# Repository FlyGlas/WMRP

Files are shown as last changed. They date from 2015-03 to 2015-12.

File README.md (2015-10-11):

# Hardware and Arduino Code for DIY WMRP-Solder Station

Video: https://www.youtube.com/watch?v=le2HaKJ6B1A

If you have any questions, please feel free to contact me: flyglas (at) gmail (dot) com

__Features:__
* low offset op amp for soldering tip temperature measurement with type D thermocouple
* cold junction compensation using the PTC (KTY82-110) included in the WMRP soldering pencil
* input voltage measurement (for use with 3 cell lipo battery)
* soldering pencil current measurement 
* recognizing if the soldering pencil rests in the stand (--> standby)
* 3 buttons for save and recall temperature values
* rotary encoder to set soldering temperature
* illuminated 16x2 character LCD module
* USB for debugging and firmware update
* clean and small enclosure
* 4mm safety socket for +12V power input and a protective earth socket for connection to ESD protection

The BOM in the layout folder includes only the parts on the PCB(s).

__Parts (not on PCB):__
* lcd display from ebay "Blue I2C 1602"
* modified connector "Amphenol T 3437 000" (--> http://www.mikrocontroller.net/topic/143288#1500819)
* 4mm safety sockets (red, black, green/yellow) or any other suitable connector
* rotary encoder knob
* display frame "EA027-2UKE"
* aluminium enclosure "Proma 131020"

__Info:__
* close jumper JP1 (activates pullup resistors for I2C wires)
* close jumper JP3 (connection between power ground and analog ground)
* leave jumper JP2 open (alternative for JP3)

__Photos:__
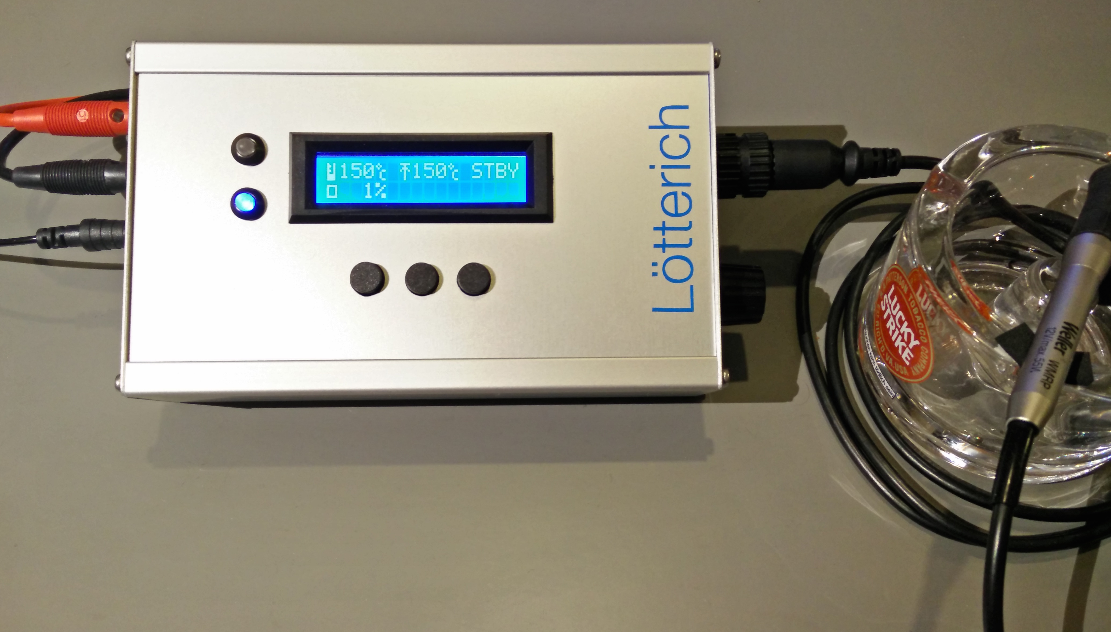
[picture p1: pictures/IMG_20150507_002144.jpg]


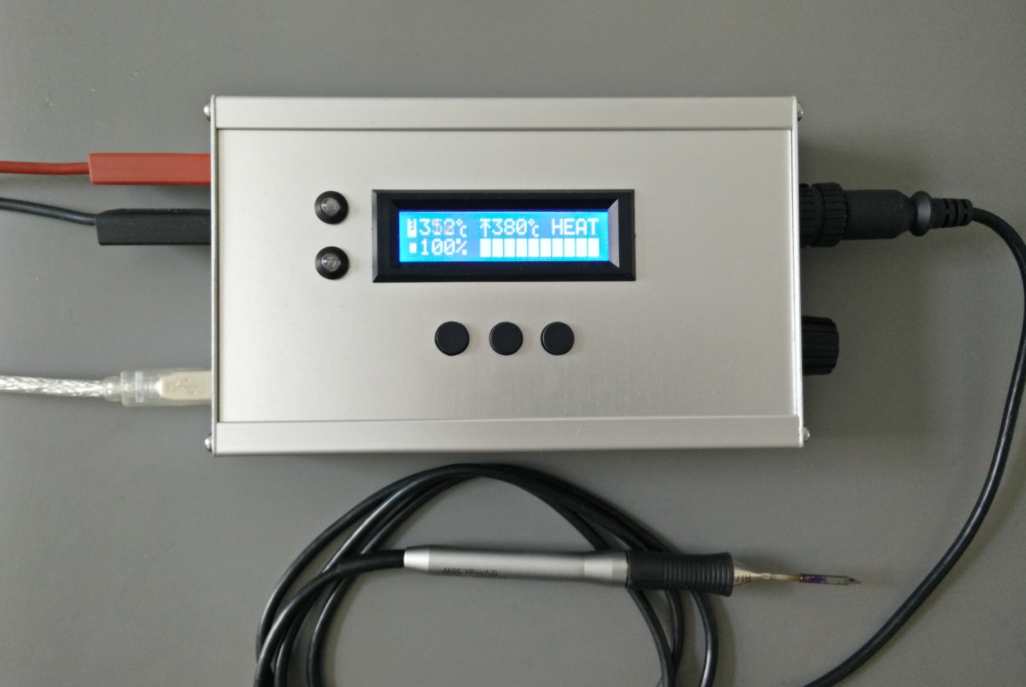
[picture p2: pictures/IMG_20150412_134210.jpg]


The PCB is a little bit dirty. The Isopropanol was empty and now everything is in the enclosure.
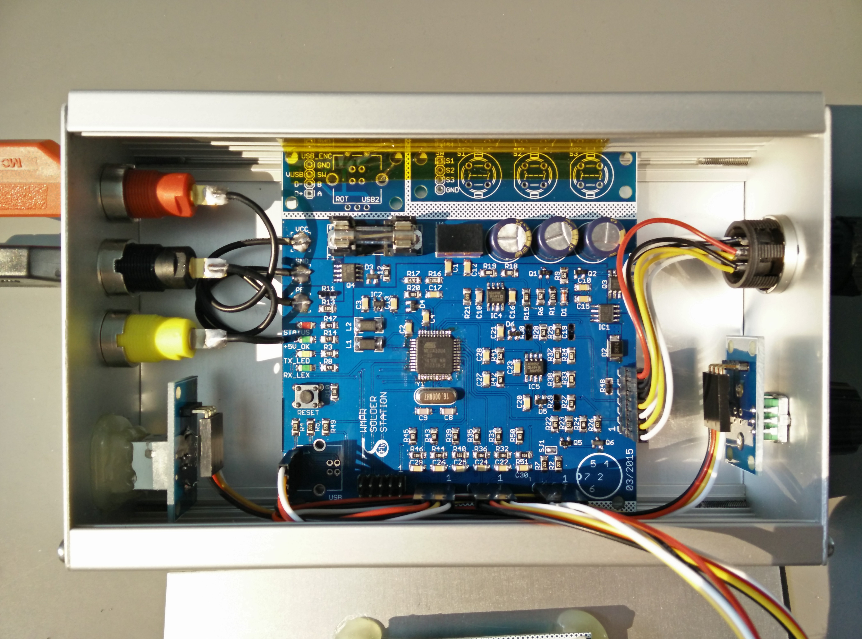
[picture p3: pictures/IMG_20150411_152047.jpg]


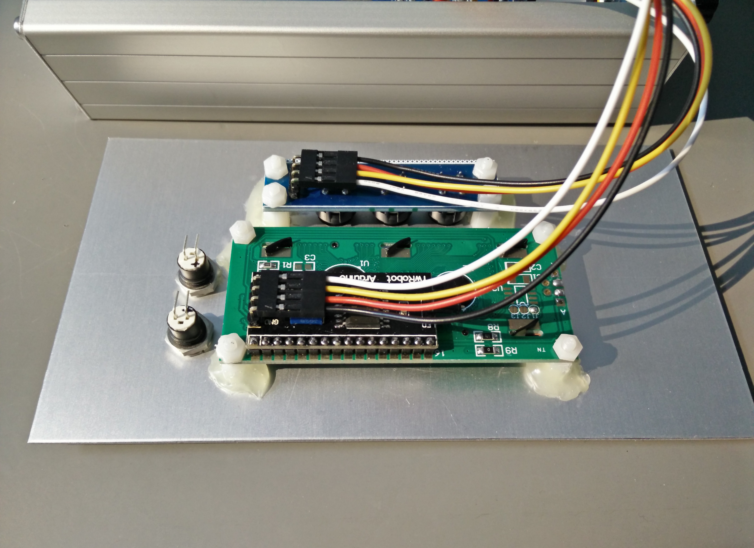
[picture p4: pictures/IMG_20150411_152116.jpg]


Stand for enclosure Proma 131020:
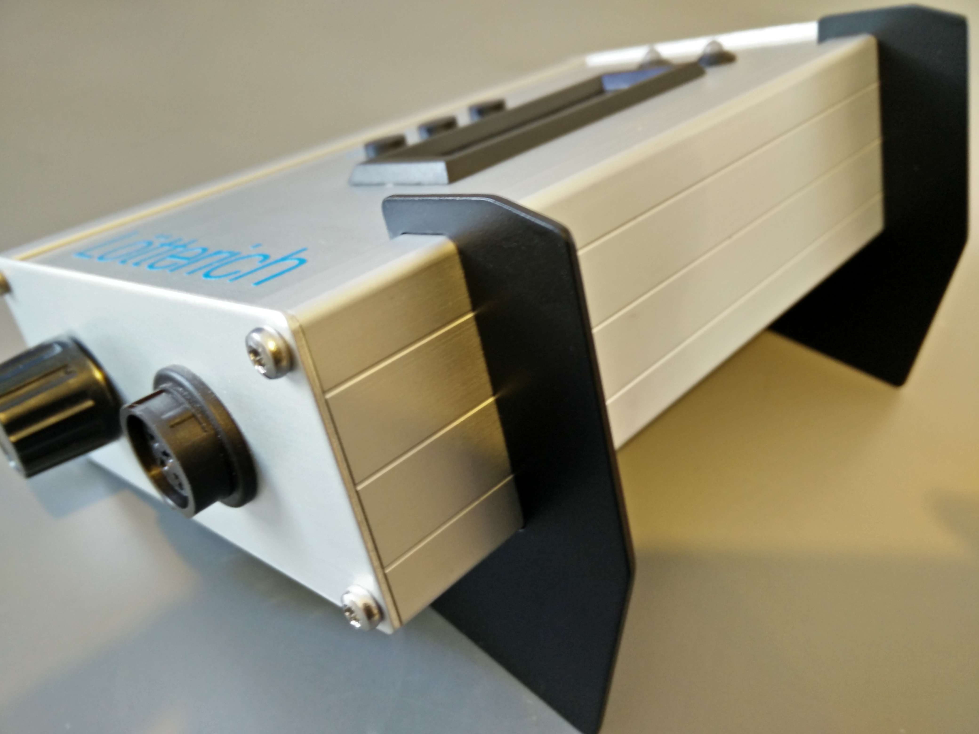
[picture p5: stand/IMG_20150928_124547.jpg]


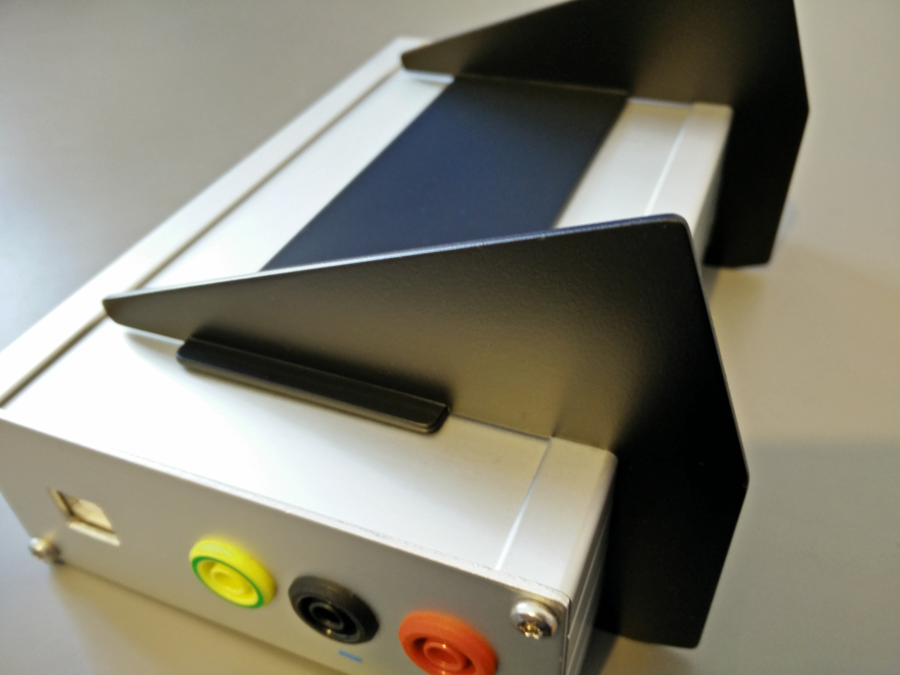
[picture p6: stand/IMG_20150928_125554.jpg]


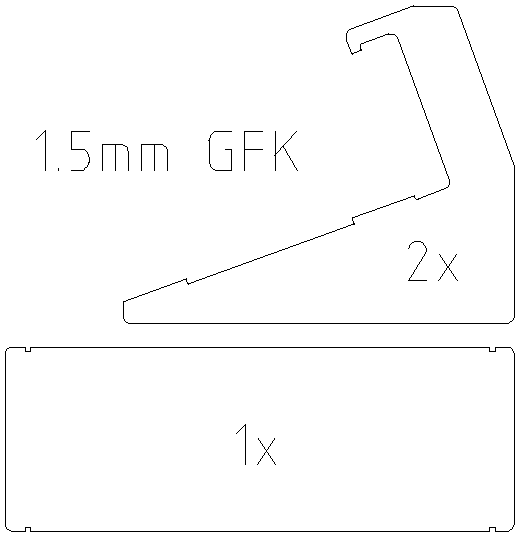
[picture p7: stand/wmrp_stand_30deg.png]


__First picture of a replica:__

Thank you Dennis for the nice conversation and the picture.
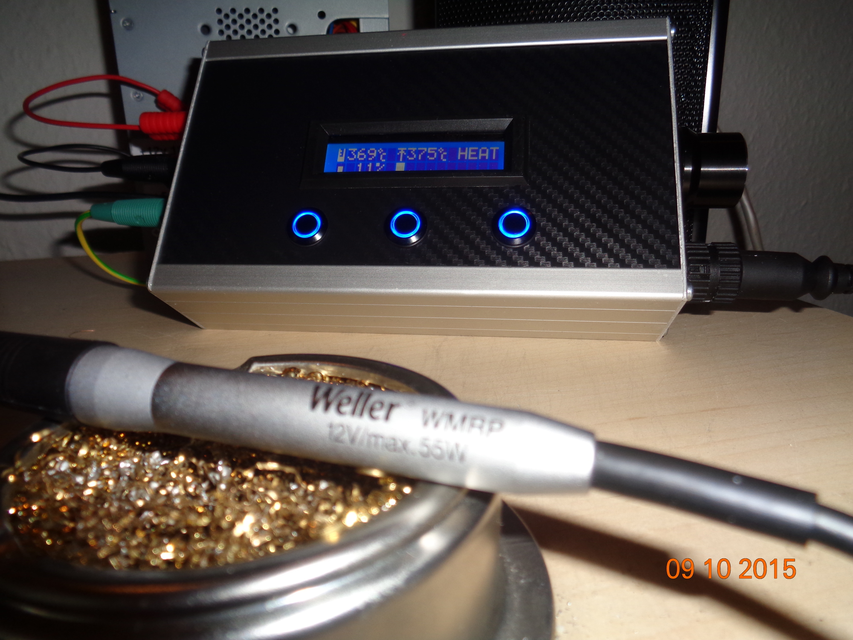
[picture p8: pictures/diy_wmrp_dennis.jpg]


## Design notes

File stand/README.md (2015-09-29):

This folder contains pictures of the stand and the dxf-file for production.

The three parts of the stand were milled from a 1.5mm GFRP-plate, glued together with cyanoacrylate adhesive and painted with matt black spray paint.

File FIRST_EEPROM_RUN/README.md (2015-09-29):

This arduino sketch writes the default temperature value of 375 deg C to the whole EEPROM of the microcontroller.
First-time operation is also possible without loading this sketch.

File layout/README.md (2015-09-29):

This folder contains the original eagle board data and schematic diagram, gerbers, bill of materials, schematic diagram as pdf and component mounting diagram.

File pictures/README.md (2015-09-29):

This folder contains pictures of the diy wmrp soldering station and the pin assignment/internal circuit of the wmrp handle.

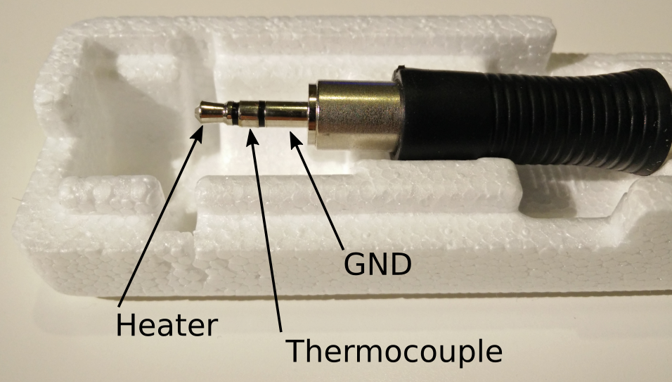
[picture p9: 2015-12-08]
pictures/tip_connector.png

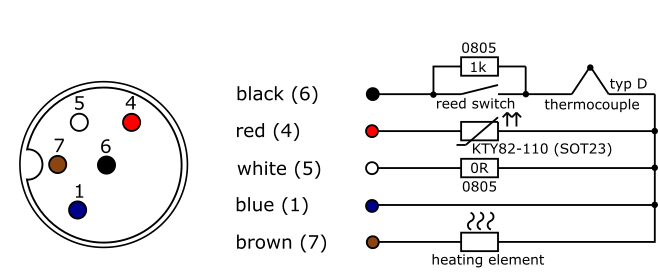
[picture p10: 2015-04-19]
pictures/pin_assignment_wmrp_en.png

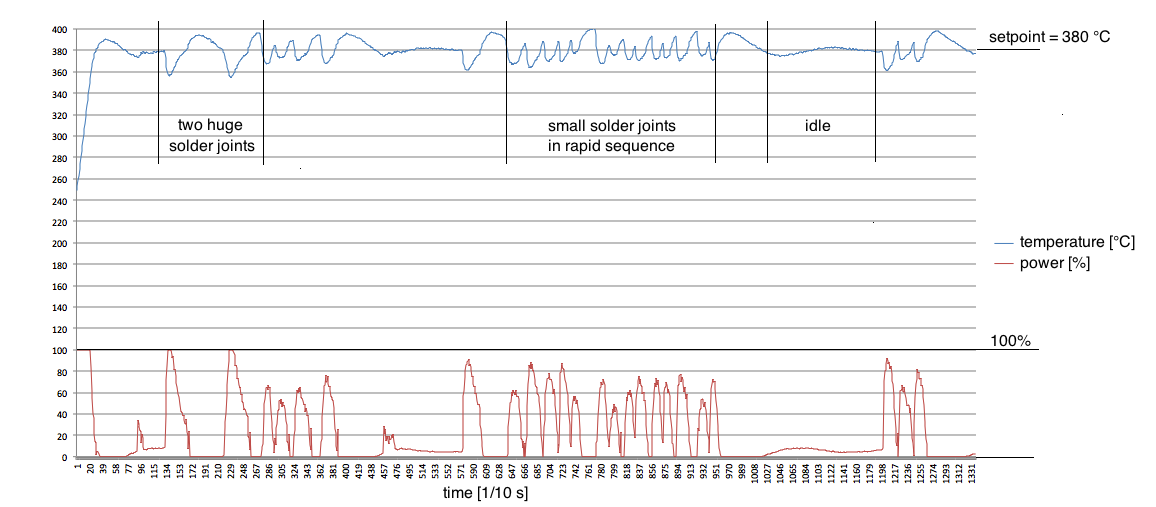
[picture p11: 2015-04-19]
pictures/temp_power_diagram.png

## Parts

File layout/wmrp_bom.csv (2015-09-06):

Qty | Value | Device | Package | Parts | Description | CONRAD | REICHELT | VOELKNER | FARNELL
1 | 100R 0.1% | R-EU_M1206 | M1206 | R33 | RESISTOR; European symbol |  | SPR-1206 100
2 | 100k | R-EU_R1206 | R1206 | R1; R22 | RESISTOR; European symbol |  | SMD 1/4W 100K
2 | 100k 0.1% | R-EU_M1206 | M1206 | R18; R19 | RESISTOR; European symbol |  | SPR-1206 100K
13 | 100n | C-EUC1206 | C1206 | C1; C2; C3; C4; C6; C10; C12; C13; C15; C16; C17; C23; C32 | CAPACITOR; European symbol |  | X7R-G1206 100N
16 | 10k | R-EU_R1206 | R1206 | R10; R12; R20; R24; R31; R32; R35; R36; R39; R40; R43; R44; R45; R46; R50; R51 | RESISTOR; European symbol |  | SMD 1/4W 10K
2 | 10k 0.1% | R-EU_M1206 | M1206 | R34; R37 | RESISTOR; European symbol |  | SPR-1206 10;0K
10 | 10n | C-EUC1206 | C1206 | C20; C21; C22; C24; C25; C26; C27; C28; C29; C30 | CAPACITOR; European symbol |  | X7R-G1206 10N
2 | 10u | INDUCTOR1206H* | INDUCTOR-1206 | L1; L2 | Inductors |  | L-1812AF 10åµ
1 | 12V | ZENER-DIODESOT23 | SOT23 | D3 | Z-Diode |  | SMD ZD 12
1 | 12k 0.1% | R-EU_R1206 | R1206 | R16 | RESISTOR; European symbol |  | SPR-1206 12;0K
1 | 16Mhz | CRYSTALHC49US | HC49US | Y1 | Various standard crystals. Proven footprints. |  | 16;0000-HC49U-S
1 | 1M | R-EU_R1206 | R1206 | R13 | RESISTOR; European symbol |  | SMD 1/4W 1;0M
1 | 1N4148 | DIODE-MINIMELF | MINIMELF | D1 | DIODE |  | 1N 4148 SMD
1 | 1k 0.1% | R-EU_M1206 | M1206 | R15 | RESISTOR; European symbol |  | SPR-1206 1;00K
1 | 1n | C-EUC1206 | C1206 | C18 | CAPACITOR; European symbol |  | NPO-G1206 1;0N
1 | 1u | C-EUC1206 | C1206 | C5 | CAPACITOR; European symbol |  | X7R-G1206 1;0/50
3 | 22R | R-EU_R1206 | R1206 | R4; R5; R49 | RESISTOR; European symbol |  | SMD 1/4W 22
2 | 22p | C-EUC1206 | C1206 | C8; C9 | CAPACITOR; European symbol |  | NPO-G1206 22P
3 | 2k2 | R-EU_R1206 | R1206 | R2; R7; R26 | RESISTOR; European symbol |  | SMD 1/4W 2;2K
2 | 2k2 0.1% | R-EU_M1206 | M1206 | R21; R25 | RESISTOR; European symbol |  | SPR-1206 2;20K
3 | 330u | CAP_POLPTH4 | CPOL-RADIAL-1000UF-25V | C7; C11; C14 | Capacitor Polarized |  | RAD FC 330/25
1 | 3R6 | R-EU_M1206 | M1206 | R52 | RESISTOR; European symbol |  | SMD 1/4W 3;6
1 | 3n3 | C-EUC1206 | C1206 | C31 | CAPACITOR; European symbol |  | X7R-G1206 3;3N
1 | 43k 0.1% | R-EU_M1206 | M1206 | R38 | RESISTOR; European symbol |  | SPR-1206 43;0K
4 | 470R | R-EU_R1206 | R1206 | R3; R8; R14; R47 | RESISTOR; European symbol |  | SMD 1/4W 470
1 | 4k7 0.1% | R-EU_R1206 | R1206 | R17 | RESISTOR; European symbol |  | SPR-1206 4;70K
7 | 5k6 | R-EU_M1206 | M1206 | R6; R9; R23; R27; R28; R41; R42 | RESISTOR; European symbol |  | SMD 1/4W 5;6K
1 | 6A | SH22;5 | SH22;5 | F1 | FUSE HOLDER grid 22;5 mm; OGN0031 8201; Schurter (Buerklin) |  | PL OGN-22;5
1 | ACS712ELCTR-20A-T | ACS712 | SO08 | IC1 | Hall-effect-based isolated linear current sensor |  |  |  | ACS712ELCTR-20A-T
2 | AD8552 | OPAMP-DUALU | SO08 | IC4; IC5 | Generic op-amp footprint |  | AD 8552 AR
1 | ADR392 | ADR392 | SOT23-5 | IC2 | 4.096 V Micropower; Low Noise Precision Voltage Reference with Shutdown | 1250814 - 62 |  | A376911
1 | ATMEGA32U4TQFP-44 | ATMEGA32U4TQFP-44 | TQFP44 | IC3 | Atmel 44-pin 8-bit Microcontroller with 32KBytes of ISP Flash and USB Controller |  |  | A886841
1 | AVR_SPI_PROG | AVR_SPI_PROG | AVR_ICSP | ISP | AVR 10-pin ICSP Header |  | MPE 087-2-010
1 | B240F | MBRS130LT3 | SMB | D2 | Schottky Power Rectifier |  | B 240 F
3 | BAV99 | BAV99 | SOT23 | D4; D5; D6 | Small Signal Diode |  | BAV 99 SMD
3 | BC817-40 | TRANSISTOR_NPNSOT23-3 | SOT23-3 | Q1; Q2; Q5 | Generic NPN BJT |  | BC 817-40 SMD
3 | DT6 | DT6 | DT6 | S1; S2; S3 | ITT SWITCH |  |  | D76189
1 | IRF7413 | IRF7413 | SO-08 | Q4 | N-Channel HEXFETå¨ Power MOSFET |  | IRF 7413
1 | IRF7416 | IRF7416 | SO-08 | Q3 | P-Channel HEXFETå¨ Power MOSFET |  | IRF 7416
1 | IRLML6402 | MOSFET-PCHANNELSMD | SOT23-3 | Q6 | Generic PMOSFET |  | IRLML 6402
1 | ROTARTY_ENCODER | ROTARTY_ENCODER | ROTARY_ENC_PLAIN | ROT | Simple no LED rotary encoder |  |  | W32173
1 | SW | SWITCH-MOMENTARY-2PTH | TACTILE-PTH | RESET | Various NO switches- pushbuttons; reed; etc |  | TASTER 9302
1 | TSR_1-2450 | TSR_1-2450 | TSR-1 | U1 | TRACO TSR-1 Series |  | TSR 1-2450
1 | USB-B | USBPTH | USB-B-PTH | USB | USB Connectors |  | USB BW
1 | USBPTH-VERTICAL | USBPTH-VERTICAL | USB-B-PTH-VERTICAL | USB2 | USB Connectors |  | USB BG
2 | green | LEDCHIPLED_1206 | CHIPLED_1206 | +5V_OK; RX_LEX | LED |  | SMD-LED 1206 GN
1 | red | LEDCHIPLED_1206 | CHIPLED_1206 | STATUS | LED |  | SMD-LED 1206 RT
1 | yellow | LEDCHIPLED_1206 | CHIPLED_1206 | TX_LED | LED |  | SMD-LED 1206 GE
1 | DO NOT INSTALL | C-EUC1206 | C1206 | C19 | CAPACITOR; European symbol
2 | DO NOT INSTALL | R-EU_M1206 | M1206 | R29; R30 | RESISTOR; European symbol
2 | DO NOT INSTALL | R-EU_R1206 | R1206 | R11; R48 | RESISTOR; European symbol

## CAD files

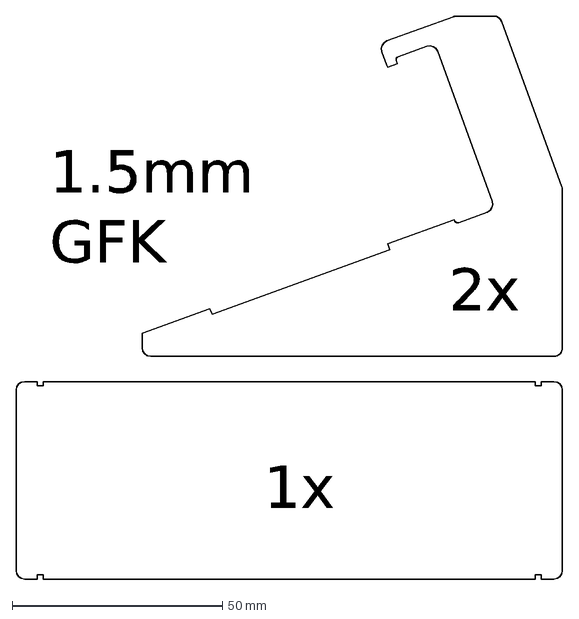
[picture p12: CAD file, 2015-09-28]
stand/wmrp_stand_30deg.dxf
2x
1.5mm GFK
1x

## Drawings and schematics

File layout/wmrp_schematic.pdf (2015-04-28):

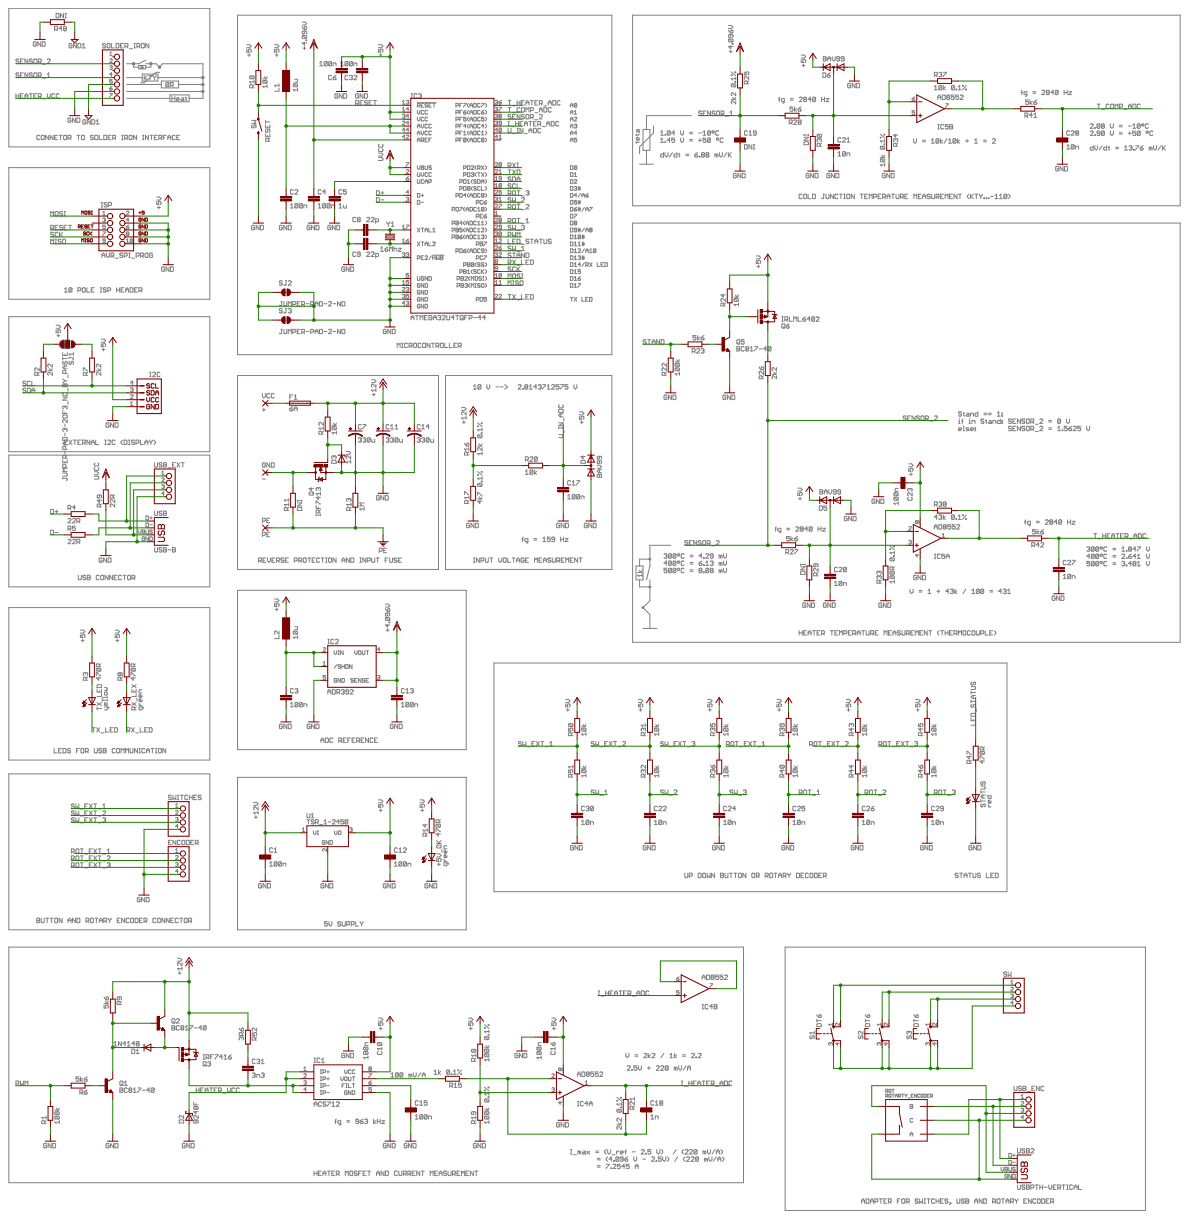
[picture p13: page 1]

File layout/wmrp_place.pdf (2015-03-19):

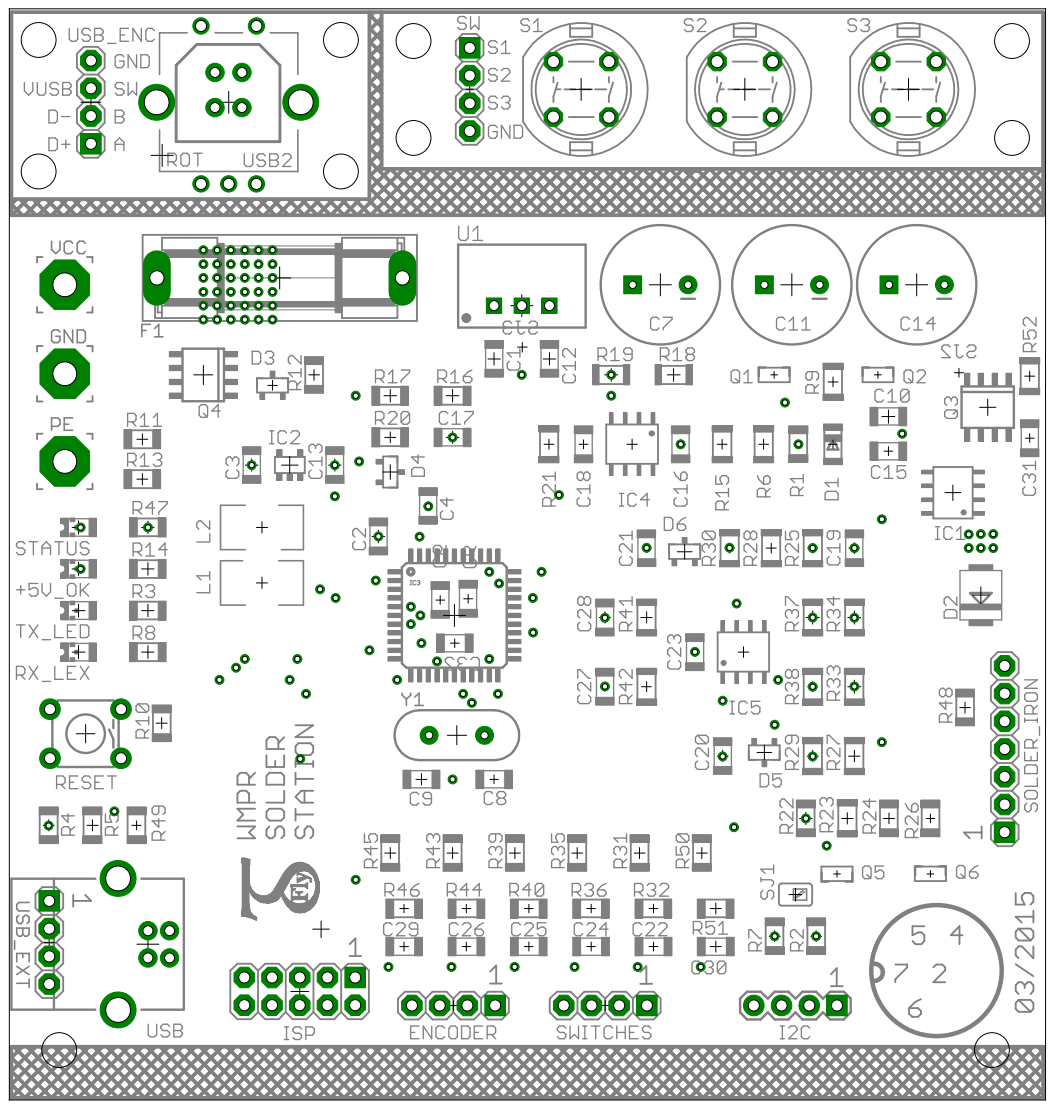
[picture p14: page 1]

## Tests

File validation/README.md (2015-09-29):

This folder contains the measurements of the turn-on und off behavior of the highside switch with and without a RC-snubber circuit.

Settling time of the thermocouple amplifier output in the heating pause is about 1.8 ms (without picture). The settling time is taken into account in the source code with a heating pause before the measurement.

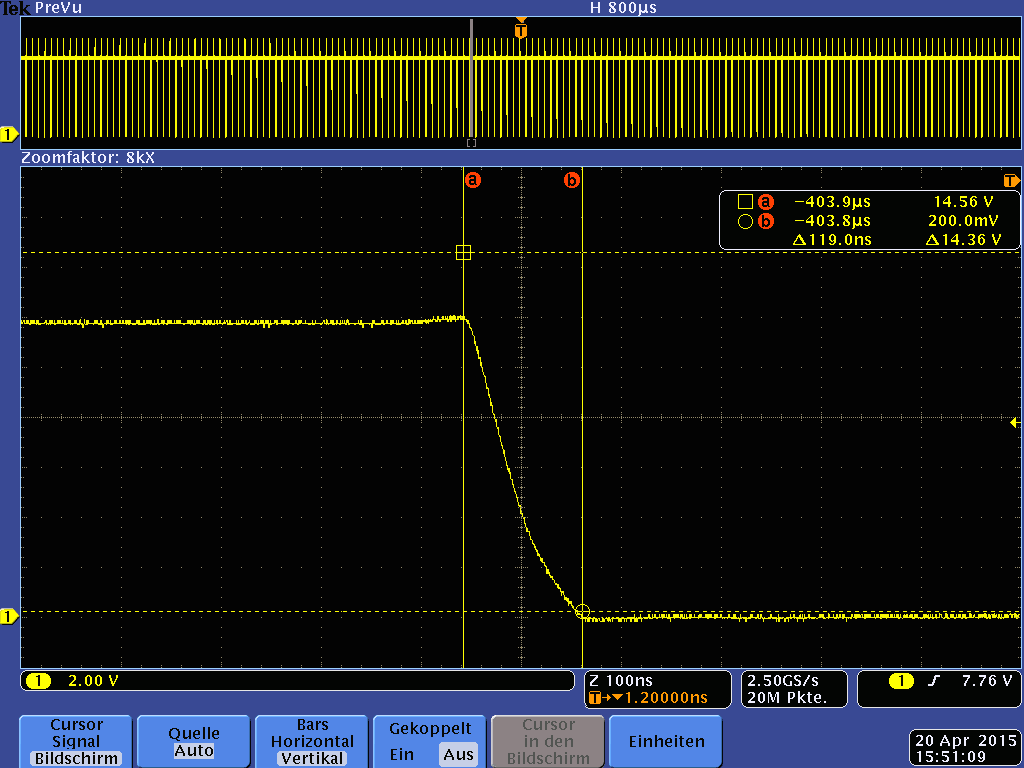
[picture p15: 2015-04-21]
validation/RC_Snubber_3n3_3R6/turn_on.png

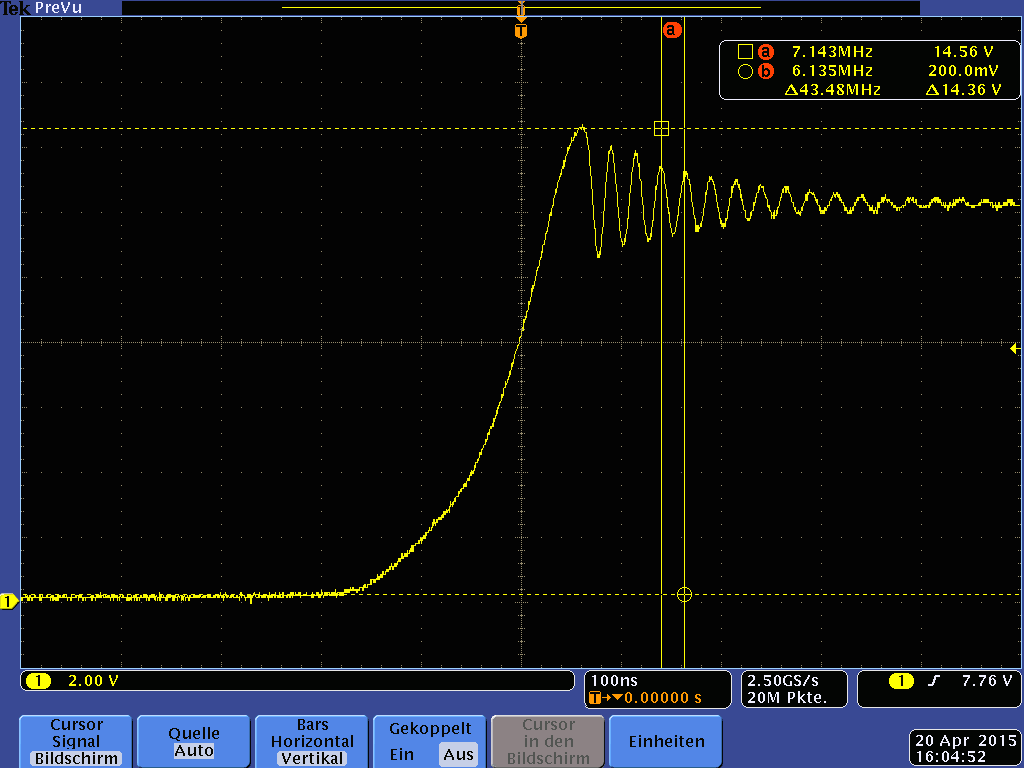
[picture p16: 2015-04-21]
validation/RC_Snubber_3n3_3R6/turn_off_without_snubber.png

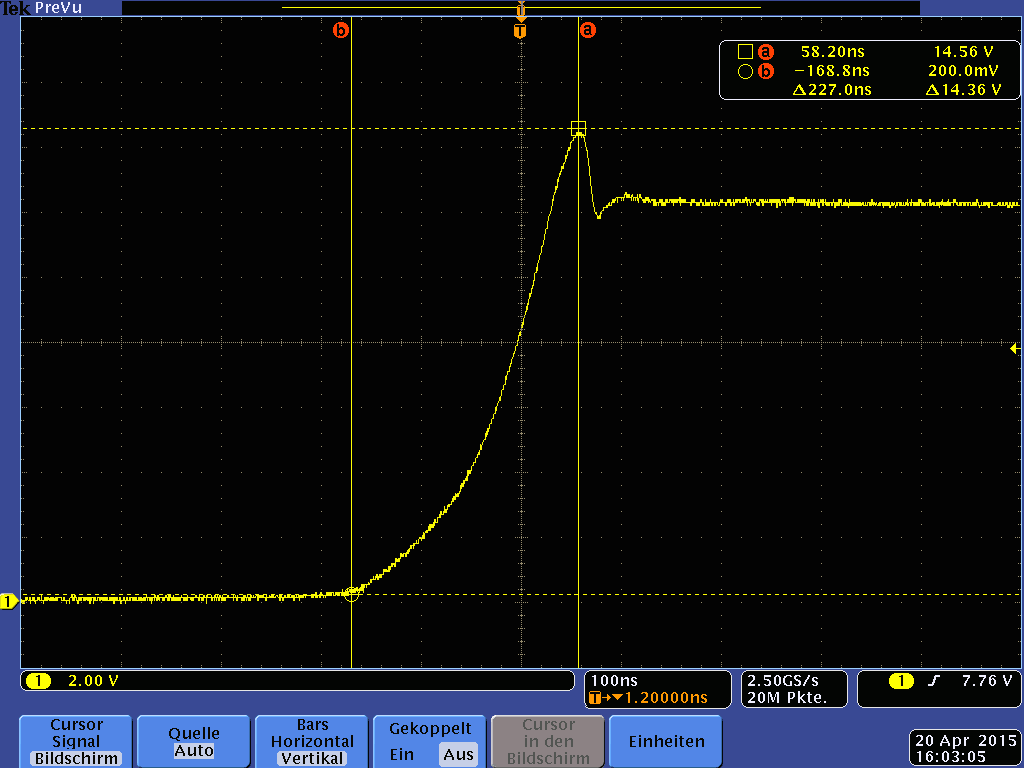
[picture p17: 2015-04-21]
validation/RC_Snubber_3n3_3R6/turn_off_with_snubber.png

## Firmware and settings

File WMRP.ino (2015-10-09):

// some preprocessor defines
#define SW_VERSION      "Version 1.3c"
#define DEBUG           true
//DIGITAL INPUT PINS
// Values after the // are the one for my pcb. Other for debugging on Arduino Uno!
#define PIN_SW_1         12
#define PIN_SW_2         5
#define PIN_SW_3         9
#define PIN_ROT_A        8
#define PIN_ROT_B        6
#define PIN_ROT_SW       4

#define DEBUG_LED        11 // STATUS_LED

//ADC INPUT PINS
#define PIN_ADC_T_GRIP   A1
#define PIN_ADC_T_TIP    A0
#define PIN_ADC_U_IN     A4
#define PIN_ADC_I_HEATER A3
#define PIN_ADC_STAND    A2

//OUTPUT PINS
#define PIN_HEATER       10
#define PIN_STAND        13
//#define PIN_I2C_SDA    2
//#define PIN_I2C_SCL    3
//#define PIN_MOSI       16
//#define PIN_MISO       17
//#define PIN_SCK        15
//#define PIN_RXI        0
//#define PIN_TXO        1

//TIMES
#define TIMER1_PERIOD_US        50 //20KHz
#define DELAY_BEFORE_MEASURE_MS 5
#define TIME_SW_POLL_MS         10
#define TIME_TUI_MEAS_MS        100
#define TIME_SERIAL_MS          500
#define TIME_LCD_MS             500
#define TIME_CYCLECOUNT_MS      1000
#define TIME_EEPROM_WRITE_MS    30000
#define TIME_STAND_MS           500
#define DELAY_BEFORE_STAND_MS   5
#define TIME_ERROR_MS           50
#define TIME_BLINK_LCD          150
#define TIME_SLEEP_S            360 //60*6
#define TIME_VERSION            2000

//THRESHOLDS
#define THRESHOLD_STAND         300      //adc value
#define ERROR_COUNTER_THRESHOLD 30       //* TIME_ERROR_MS (50) = 1500ms
#define VOLTAGE_TRESHOLD        10500000 //10.5V

//PID CONTROL - SOLDERING
#define CNTRL_P_GAIN            40.0
#define CNTRL_I_GAIN            8.0
#define CNTRL_D_GAIN            0.0

//PID CONTROL - TARGET TEMP && PWM < 10%
#define BAND_TARGET_TEMP_GRAD   4
#define BAND_MAX_PWM_PERCENT    10.0
#define BAND_P_GAIN             10.0
#define BAND_I_GAIN             2.0
#define BAND_D_GAIN             0.0

//TEMPERATURES
#define STDBY_TEMP_DEG         150
#define MIN_TARGET_TEMP_DEG    150
#define MAX_TARGET_TEMP_DEG    450

//PWM MAX (1024 in normal operation; 0-1024 for testing purposes with reduced power)
#define PWM_MAX_VALUE          1024

//ADC TO TIP TEMPERATURE CONVERSION --> OLD
//#define ADC_TO_T_TIP_A0  -1176200 //                  T[degC] = -1176.2 + 3.34 * SQRT(14978 * U[mV] + 130981)
//#define ADC_TO_T_TIP_A1  3340     //                    U[mV] = adc_value * 4mV * 1/OPAMP_T_TIP_GAIN
//#define ADC_TO_T_TIP_A2  139      //           10^3 * T[degC] = -1176200 + 3340 * SQRT(139 * adc_value + 130981)
//#define ADC_TO_T_TIP_A3  130981

//ADC TO GRIP TEMPERATURE CONVERSION
#define ADC_TO_T_GRIP_A0 289      //                  T[degC] = (U[V] - 1.1073) * 1000/6.91
#define ADC_TO_T_GRIP_A1 -160246  //                     U[V] = adc_value * 4 V/1000 * 1/OPAMP_T_GRIP_GAIN
//                                             10^3 * T[degC] = adc_value * 289.435 - 160246

//ADC TO INPUT VOLTAGE CONVERSION
#define ADC_TO_U_IN_A0 14213      //                 U_adc[V] = U_in[V] * 4700/(4700 + 12000);
//                                                   U_adc[V] = adc_value * 4 V/1000
//                                                    U_in[V] = adc_value * 4 V/1000 *(4700 + 12000)/4700
//                                             10^6 * U_in[V] = adc_value * 14212,77

//ADC TO INPUT CURRENT CONVERSION
#define ADC_TO_I_HEATER_A0 18182  //                U_adc[mV] = UVCC/2[mV] + I_heater[A] * 220 mV/A
//                                                  U_adc[mV] = adc_value * 4 mV
//                                                 UVCC/2[mV] = adc_value(@i=0A) * 4 mV
//                                                I_heater[A] = (adc_value * 4 mV - UVCC/2[mV])/(220 mV/A)
//                                         10^6 * I_heater[A] = (adc_value - adc_value(@i=0A)) * 18182

//HARDWARE BASED VALUES
//#define OPAMP_T_TIP_GAIN    431.0
//#define OPAMP_T_GRIP_GAIN   2.0
//#define OPAMP_I_HEATER_GAIN 2.2

//COMPENSATION VALUE
#define ADC_T_TIP_OFFSET_COMP 21   //offset measured when thermocouple and cold junction are at the same temperature

//EEPROM ADDRESS
#define EEPROM_ADDRESS_TEMP_START   0
//#define EEPROM_ADDRESS_TEMP_END   1
#define EEPROM_ADDRESS_VAL1_START   2
//#define EEPROM_ADDRESS_VAL1_END   3
#define EEPROM_ADDRESS_VAL2_START   4
//#define EEPROM_ADDRESS_VAL2_END   5
#define EEPROM_ADDRESS_VAL3_START   6
//#define EEPROM_ADDRESS_VAL3_END   7


///////////////////////////////////////////////////////////////////////////////////////////////////////////////////////////////////////////////////

#include "TimerOne.h"          //Version r11   --> http://code.google.com/p/arduino-timerone/
#include <EEPROM.h>            //Included in Arduino IDE Version 1.6.0
#include <Wire.h>              //Included in Arduino IDE Version 1.6.0
#include <LiquidCrystal_I2C.h> //Version 1.2.1 or 1.3.3 --> https://bitbucket.org/fmalpartida/new-liquidcrystal/downloads
LiquidCrystal_I2C lcd(0x27, 2, 1, 0, 4, 5, 6, 7, 3, POSITIVE);  // Set the LCD I2C address
#include <Encoder.h>           //Version 1.2   --> http://www.pjrc.com/teensy/td_libs_Encoder.html
Encoder enc(PIN_ROT_A, PIN_ROT_B);

//GLOBAL VARIABLES
long    temperature_tip_absolute;
int adc_temperature_tip_relative;
int adc_temperature_tip_relative_old;
int adc_temperature_grip;
long    temperature_grip;
int adc_voltage_input;
long    voltage_input;
int adc_current_heater;
long    current_heater;

static float TempC_to_Emf_TypeD[6];
static float Emf_to_TempC_TypeD[7];

int adc_current_heater_offset;
int pwm_value;
int pwm_value_mean;
byte pwm_percent;
int temp_setpoint;
int temp_setpoint_old;
int encoder_value;

boolean state_switch[5];
boolean state_switch_old[5];// = {false, true, true, true};
byte button_count[5];

boolean meas_flag;

boolean sleep_flag;
long    sleep_counter = TIME_SLEEP_S;
boolean status_stand_reed;
boolean status_stand_manu = true;  //start with standby

boolean error_voltage;
boolean temp_flag;
boolean error_tip;
boolean no_tip;
byte error_counter;

byte pid_flag;

//variables for cycle count
int cycle;
int last_cycle;

//chars for bargraph
byte p1[8] = {
  0b10000,
  0b10000,
  0b10000,
  0b10000,
  0b10000,
  0b10000,
  0b10000,
  0b10000
};

byte p2[8] = {
  0b11000,
  0b11000,
  0b11000,
  0b11000,
  0b11000,
  0b11000,
  0b11000,
  0b11000
};

byte p3[8] = {
  0b11100,
  0b11100,
  0b11100,
  0b11100,
  0b11100,
  0b11100,
  0b11100,
  0b11100
};

byte p4[8] = {
  0b11110,
  0b11110,
  0b11110,
  0b11110,
  0b11110,
  0b11110,
  0b11110,
  0b11110
};

byte box_char[8] = {
  0b00000,
  0b00000,
  0b01110,
  0b01110,
  0b01110,
  0b01110,
  0b00000,
  0b00000
};
byte temperatur_char[8] = {
  0b10010,
  0b11010,
  0b10010,
  0b11010,
  0b10010,
  0b11110,
  0b11110,
  0b11110
};
byte gradcelsius_char[8] = {
  0b01000,
  0b10100,
  0b01000,
  0b00011,
  0B00100,
  0b00100,
  0b00100,
  0b00011
};
byte arrow_char[8] = {
  0b11111,
  0b00100,
  0b01110,
  0b10101,
  0b00100,
  0b00100,
  0b00100,
  0b00100
};

const byte eeprom_address[3] = {
  EEPROM_ADDRESS_VAL1_START,
  EEPROM_ADDRESS_VAL2_START,
  EEPROM_ADDRESS_VAL3_START
};

///////////////////////////////////////////////////////////////////////////////////////////////////////////////////////////////////////////////////
//CLASSES

//timer_over class
class timer_over {
  private:
    unsigned long _last_time;
  public:
    timer_over() {
      _last_time = 0;
    }
    boolean over(long sample_time) {
      unsigned long now = millis();
      unsigned long time_change = (now - this->_last_time);

      if (time_change >= sample_time) {
        this->_last_time = now;
        return true;
      }
      else {
        return false;
      }
    }
    boolean set_timer() {
      this->_last_time = millis();
    }
};
//timer_over class members
timer_over timer_meas;
timer_over timer_serial;
timer_over timer_lcd;
timer_over timer_switch;
timer_over timer_cyclecount;
timer_over timer_eeprom;
timer_over timer_delay_before_measure;
timer_over timer_stand;
timer_over timer_error_chk;
timer_over timer_blink_lcd;

///////////////////////////////////////////////////////////////////////////////////////////////////////////////////////////////////////////////////
//FUNCTIONS

//Original code for bargraph --> http://playground.arduino.cc/Code/LcdBarGraph
void draw_bar(int value, byte numCols, int maxValue) {
  static int prevValue;
  static byte lastFullChars;

  byte fullChars = (long)value * numCols / maxValue;
  byte mod = ((long)value * numCols * 5 / maxValue) % 5;

  int normalizedValue = (int)fullChars * 5 + mod;

  if (prevValue != normalizedValue) {

    for (byte i = 0; i < fullChars; i++) {
      lcd.write((char)0b11111111);
    }
    if (mod > 0) {
      switch (mod) {
        case 0:
          break;
        case 1:
          lcd.print((char)0);
          break;
        case 2:
          lcd.write(1);
          break;
        case 3:
          lcd.write(2);
          break;
        case 4:
          lcd.write(3);
          break;
          ++fullChars;
      }
    }
    //for (byte i = fullChars; i < lastFullChars; i++) {
    for (byte i = fullChars; i < numCols; i++) {
      lcd.write(' ');
    }

    // -- save cache
    lastFullChars = fullChars;
    prevValue = normalizedValue;
  }
}


void update_measurments() {
  //empty
}


int calculate_pid(int setpoint, int input, float kp, float ki, float kd, int sample_time, int out_max) {
  //float pid(float setpoint, float input, float kp, float ki, float kd, unsigned int sample_time, float out_max, float &i_value, float &p_value) {
  static unsigned long last_time;
  static float last_input;
  static float iterm;
  float error;
  float dterm;
  float pterm;
  float output;
  float out_min = 0;

  float sample_time_in_sec = ((float)sample_time) / 1000;

  kp = kp;
  ki = ki * sample_time_in_sec;
  kd = kd / sample_time_in_sec;

  // compute all the working error variables
  error = setpoint - input;

  // (d)erivative
  dterm = kd * (input - last_input);

  // (p)roportional
  pterm = kp * error;

  // (i)ntegral with anti wind up
  if ((dterm + pterm + iterm) <= out_max) {
    iterm += (ki * error);
  }

  if (iterm > out_max) iterm = out_max;
  else if (iterm < out_min) iterm = out_min;

  // compute PID output
  output = pterm + iterm - dterm;

  if (output > out_max) output = out_max;
  else if (output < out_min) output = out_min;

  // Remember some variables for next time
  last_input  = input;
  return (int)output;
}


float PolyEval(float x, float *Coeffs, unsigned int Degree) {
  float pol = 0.0;
  for (int i = Degree; i >= 0; i--)
  {
    pol = pol * x + Coeffs[i];
  }
  return pol;
}


long adc_to_t_grip_calc(int adc_value) {
  long t_grip = (ADC_TO_T_GRIP_A0 * (long)adc_value) + ADC_TO_T_GRIP_A1;
  //Serial.println((float)t_grip / 1000, 3);
  return t_grip;
}


long adc_to_u_in_calc(int adc_value) {
  long u_in = (ADC_TO_U_IN_A0 * (long)adc_value);
  //Serial.println((float)u_in / 1000000, 3);
  return u_in;
}


long adc_to_i_heater_calc(int adc_value, int adc_value_offset) {
  long i_heater = ADC_TO_I_HEATER_A0 * ((long)adc_value - (long)adc_value_offset);
  //Serial.println((float)i_heater / 1000000, 3);
  return i_heater;
}


void  serial_draw_line() {
  Serial.println("--------------------------------------");
}

int eeprom_read_int(int addr) {
  int value = EEPROM.read(addr) | (((int) EEPROM.read(addr + 1)) << 8);
  value = constrain(value, MIN_TARGET_TEMP_DEG, MAX_TARGET_TEMP_DEG);
  if (DEBUG) {
    Serial.print("Read from EEPROM Address: ");
    Serial.print(addr);
    Serial.print("/");
    Serial.println(addr + 1);
    Serial.print("Value: ");
    Serial.println(value);
    serial_draw_line();
  }
  return value;
}

void eeprom_write_int(int addr, int value) {
  EEPROM.write(addr, value & 0xff);
  EEPROM.write(addr + 1, (value & 0xff00) >> 8);

  if (DEBUG) {
    Serial.print("Write to EEPROM Address: ");
    Serial.print(addr);
    Serial.print("/");
    Serial.println(addr + 1);
    Serial.print("Value: ");
    Serial.println(value);
    serial_draw_line();
  }
}

///////////////////////////////////////////////////////////////////////////////////////////////////////////////////////////////////////////////////
//SETUP ROUTINE

void setup()
{
  //DEFINE COEFFICIENTS
  TempC_to_Emf_TypeD[0] =  0.0000000E+0;
  TempC_to_Emf_TypeD[1] =  9.5685256E-3;
  TempC_to_Emf_TypeD[2] =  2.0592621E-5;
  TempC_to_Emf_TypeD[3] = -1.8464576E-8;
  TempC_to_Emf_TypeD[4] =  7.9498033E-12;
  TempC_to_Emf_TypeD[5] = -1.4240735E-15;


  Emf_to_TempC_TypeD[0] =  7.407745239E-1;
  Emf_to_TempC_TypeD[1] =  9.827743947E+1;
  Emf_to_TempC_TypeD[2] = -1.223274978E+1;
  Emf_to_TempC_TypeD[3] =  1.930483337E+0;
  Emf_to_TempC_TypeD[4] = -1.825482304E-1;
  Emf_to_TempC_TypeD[5] =  9.140368153E-3;
  Emf_to_TempC_TypeD[6] = -1.851682378E-4;

  //USE EXTERNAL AREF
  analogReference(EXTERNAL);

  //OUTPUT PINS
  pinMode(PIN_HEATER, OUTPUT);
  pinMode(PIN_STAND, OUTPUT);

  pinMode(DEBUG_LED, OUTPUT);


  //DIGITAL INPUT PINS
  pinMode(PIN_SW_1, INPUT);
  digitalWrite(PIN_SW_1, HIGH);
  pinMode(PIN_SW_2, INPUT);
  digitalWrite(PIN_SW_2, HIGH);
  pinMode(PIN_SW_3, INPUT);
  digitalWrite(PIN_SW_3, HIGH);
  pinMode(PIN_ROT_A, INPUT);
  digitalWrite(PIN_ROT_A, HIGH);
  pinMode(PIN_ROT_B, INPUT);
  digitalWrite(PIN_ROT_B, HIGH);
  pinMode(PIN_ROT_SW, INPUT);
  digitalWrite(PIN_ROT_SW, HIGH);

  //ADC INPUT PINS
  pinMode(PIN_ADC_T_GRIP, INPUT);
  pinMode(PIN_ADC_U_IN, INPUT);
  pinMode(PIN_ADC_I_HEATER, INPUT);
  pinMode(PIN_ADC_STAND, INPUT);


  Timer1.initialize(TIMER1_PERIOD_US); //initialize timer1
  Timer1.attachInterrupt(isr_routine); //attaches callback() as a timer overflow interrupt
  Timer1.pwm(PIN_HEATER, 0);           //setup pwm pin, 0 % duty cycle

  delay(100);
  adc_current_heater_offset = analogRead(PIN_ADC_I_HEATER); //read adc offset for current measurement @ I_HEATER = 0 A
  adc_temperature_grip      = analogRead(PIN_ADC_T_GRIP);   //read grip temperatur to avoid error at startup

  temp_setpoint = eeprom_read_int(EEPROM_ADDRESS_TEMP_START); //read eeprom
  temp_setpoint_old = temp_setpoint;

  enc.write(temp_setpoint);   //set encoder value to temp_setpoint

  Serial.begin(115200);       //start serial communication
  Serial.println(SW_VERSION); //print software version

  delay(10);
  lcd.begin(16, 2);      //initialize the lcd for 16 chars 2 lines
  lcd.createChar(0, p1); //create chars for bargraph
  lcd.createChar(1, p2);
  lcd.createChar(2, p3);
  lcd.createChar(3, p4);
  lcd.createChar(4, box_char);
  lcd.createChar(5, temperatur_char);
  lcd.createChar(6, gradcelsius_char);
  lcd.createChar(7, arrow_char);
  lcd.clear();
  delay(10);

  //start screen on lcd
  lcd.setCursor(2, 0); //Start at character 0 on line 0
  lcd.write("WMRP STATION");
  lcd.setCursor(2, 1); //Start at character 0 on line 0
  lcd.write(SW_VERSION);
  delay(TIME_VERSION);
  lcd.clear();
}

void isr_routine()
{
  //isr routine - not used now
}
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

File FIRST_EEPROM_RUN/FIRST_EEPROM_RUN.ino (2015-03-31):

//Set every EEPROM temperature value to 375 deg C

#include <EEPROM.h>

int addr = 0;

void setup()
{
}

void loop()
{
  int val1 = 1;
  int val2 = 119;

  if (addr % 2 == 1) {
    EEPROM.write(addr, val1);
  }
  else {
    EEPROM.write(addr, val2);
  }

  addr = addr + 1;
  if (addr == 512)
    addr = 0;

  delay(100);
}

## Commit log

2015-03-15 Arduino file
2015-03-23 small changes
    [wmrp_bom.csv]
2015-03-29 corrected wrong part
    [wmrp_bom.csv]
2015-04-11 PID improvement
2015-04-12 some changes
    start with standby; show actual temperature only when in the right
    limits and no error flag is true
    [WMRP.ino]
2015-04-16 under voltage lockout
2015-04-28 Snubber added
    [wmrp_bom.csv]
2015-09-06 cleaner BOM
    [wmrp_bom.csv]
2015-09-28 stand for enclosure
    [wmrp_stand_30deg.dxf]
2015-09-29 fix temperature conversion issue
    [WMRP.ino]
